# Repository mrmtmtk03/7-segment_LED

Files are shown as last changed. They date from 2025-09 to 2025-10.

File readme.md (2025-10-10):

# 7セグメントLED回路
## 回路構成
KiCadにて回路図を作成した。
7セグメントデコーダー([TC4511BP](https://toshiba.semicon-storage.com/jp/semiconductor/product/general-purpose-logic-ics/detail.TC4511BP.html))を使用して、4つの7セグメントLEDをArduino UNOによりダイナミック点灯する回路である。
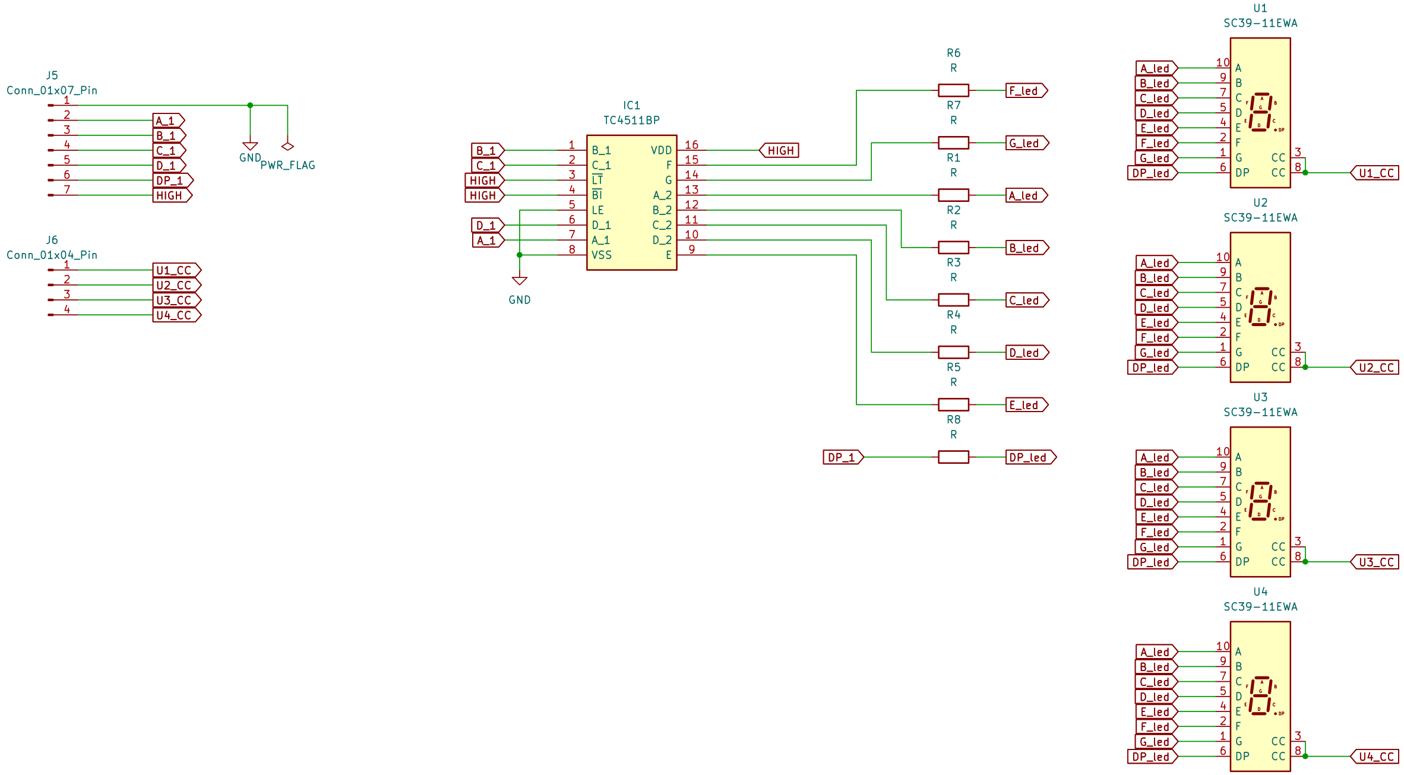
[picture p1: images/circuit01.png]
KiCadにて作成した回路図

## 使用部品
使用する7セグメントLEDはカソードコモンで、データシートより順方向電圧$`V_F=3.5\,[\mathrm{V}]`$、順方向電流の絶対最大定格は$`I_F=35\,[\mathrm{mA}]`$である。
今回は$`I_F=4.5\,[\mathrm{mA}]`$となるように抵抗1を選定し以下のようにRを330 Ωと定める。
```math
R_1=\frac{V-V_F}{I_F}=\frac{5-3.5}{0.0045}≒330\,[\mathrm{Ω}]
```
具体的な使用部品は以下の表に示す。
| 部品 | 型番 | 秋月電子販売コード |
| :--- | :--- | :---: |
| 7セグメントドライバー | TC4511BP | [114057](https://akizukidenshi.com/catalog/g/g114057/) |
| 7セグメントLED | OSL10391-LRA | [130319](https://akizukidenshi.com/catalog/g/g130319/) |
| 抵抗器 | 330 Ω | [107812](https://akizukidenshi.com/catalog/g/g107812/) |
| 丸ピンICソケット(16P) | 2227MC-16-03 | [100029](https://akizukidenshi.com/catalog/g/g100029/) |
| 細ピンヘッダー(オスL型) 1×12 | PHA-1x12RG | [111573](https://akizukidenshi.com/catalog/g/g111573/) |

なお、点灯させるためには、この他に[Arduino UNO](https://akizukidenshi.com/catalog/g/g115574/)が必要である。
## プリント基板の作成
設計した基板データは本リポジトリで公開している。
例えば、[JLCPCB](https://jlcpcb.com/)であればこの[ZIPファイル](7-segment_LED_02_kicad\production\7-segment_LED_02_kicad.zip) `7-segment_LED_02_kicad\production\7-segment_LED_02_kicad.zip`をgerber fileとしてアップロードすることで基板の発注ができる。

ただし、基板の発注内容に誤りがあった場合、その結果生じた発注者の不利益について、当方は責任を負いかねますので、十分ご注意ください。

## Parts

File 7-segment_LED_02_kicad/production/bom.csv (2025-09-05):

Designator | Footprint | Quantity | Value | LCSC Part #
GND | PinHeader_1x07_P2.54mm_Vertical | 1 | Conn_01x07_Pin
IC1 | DIP762W60P254L1975H445Q16N | 1 | TC4511BP
J6 | PinHeader_1x04_P2.54mm_Vertical | 1 | Conn_01x04_Pin
R1, R2, R3, R4, R5, R6, R7, R8 | R_Axial_DIN0207_L6.3mm_D2.5mm_P10.16mm_Horizontal | 8 | R
U1, U2, U3, U4 | Sx39-1xxxxx | 4 | SC39-11EWA

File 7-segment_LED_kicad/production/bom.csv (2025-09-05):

Designator | Footprint | Quantity | Value | LCSC Part #
GND | PinHeader_1x12_P2.54mm_Vertical | 1 | Conn_01x12_Pin
IC1 | DIP762W60P254L1975H445Q16N | 1 | TC4511BP
R1, R2, R3, R4, R5, R6, R7, R8 | R_Axial_DIN0207_L6.3mm_D2.5mm_P10.16mm_Horizontal | 8 | R
U1, U2, U3, U4 | Sx39-1xxxxx | 4 | SC39-11EWA

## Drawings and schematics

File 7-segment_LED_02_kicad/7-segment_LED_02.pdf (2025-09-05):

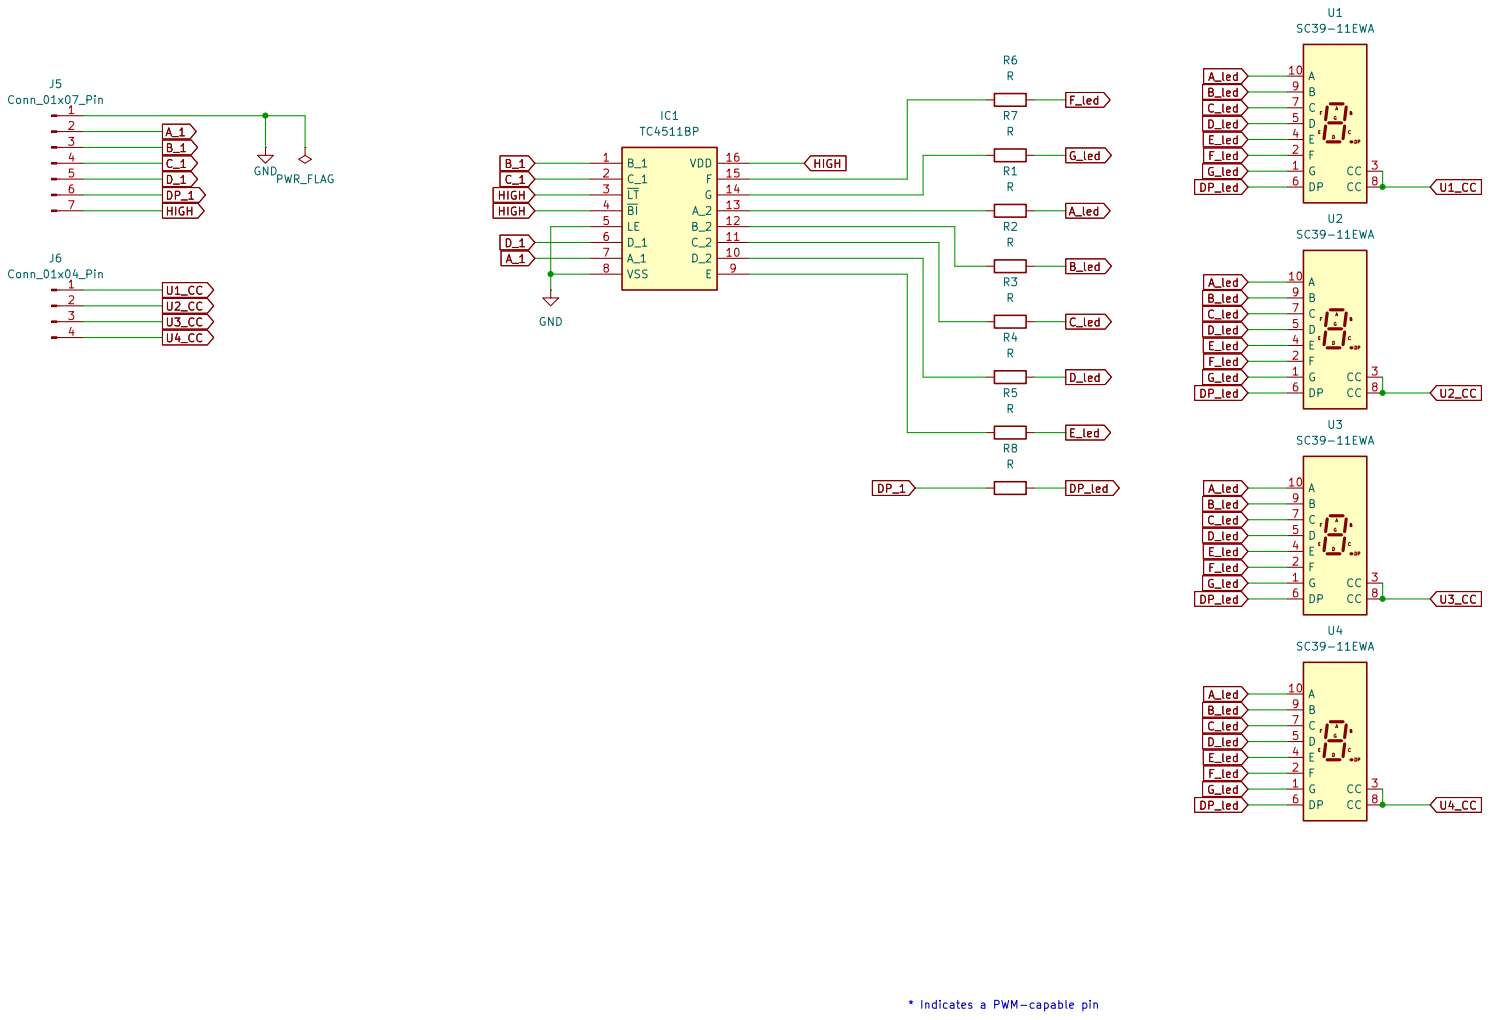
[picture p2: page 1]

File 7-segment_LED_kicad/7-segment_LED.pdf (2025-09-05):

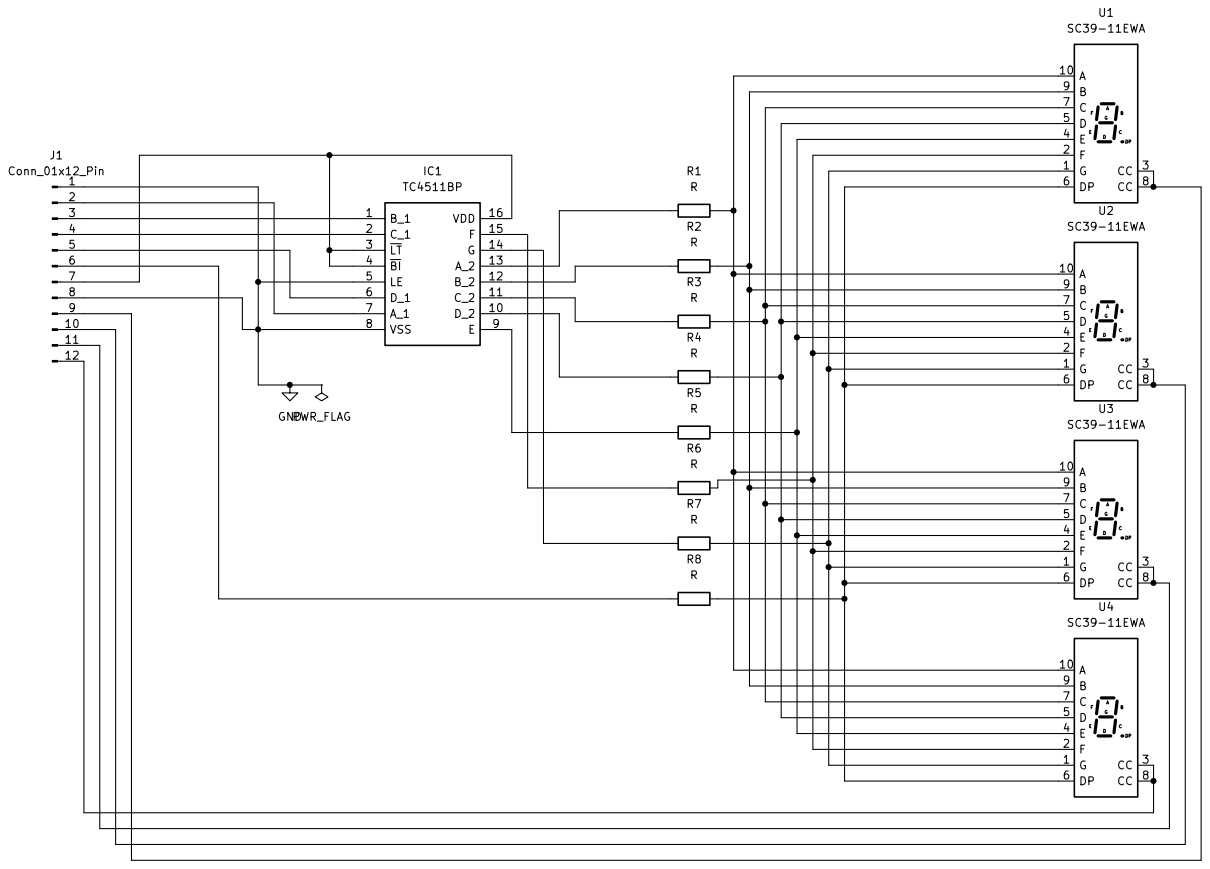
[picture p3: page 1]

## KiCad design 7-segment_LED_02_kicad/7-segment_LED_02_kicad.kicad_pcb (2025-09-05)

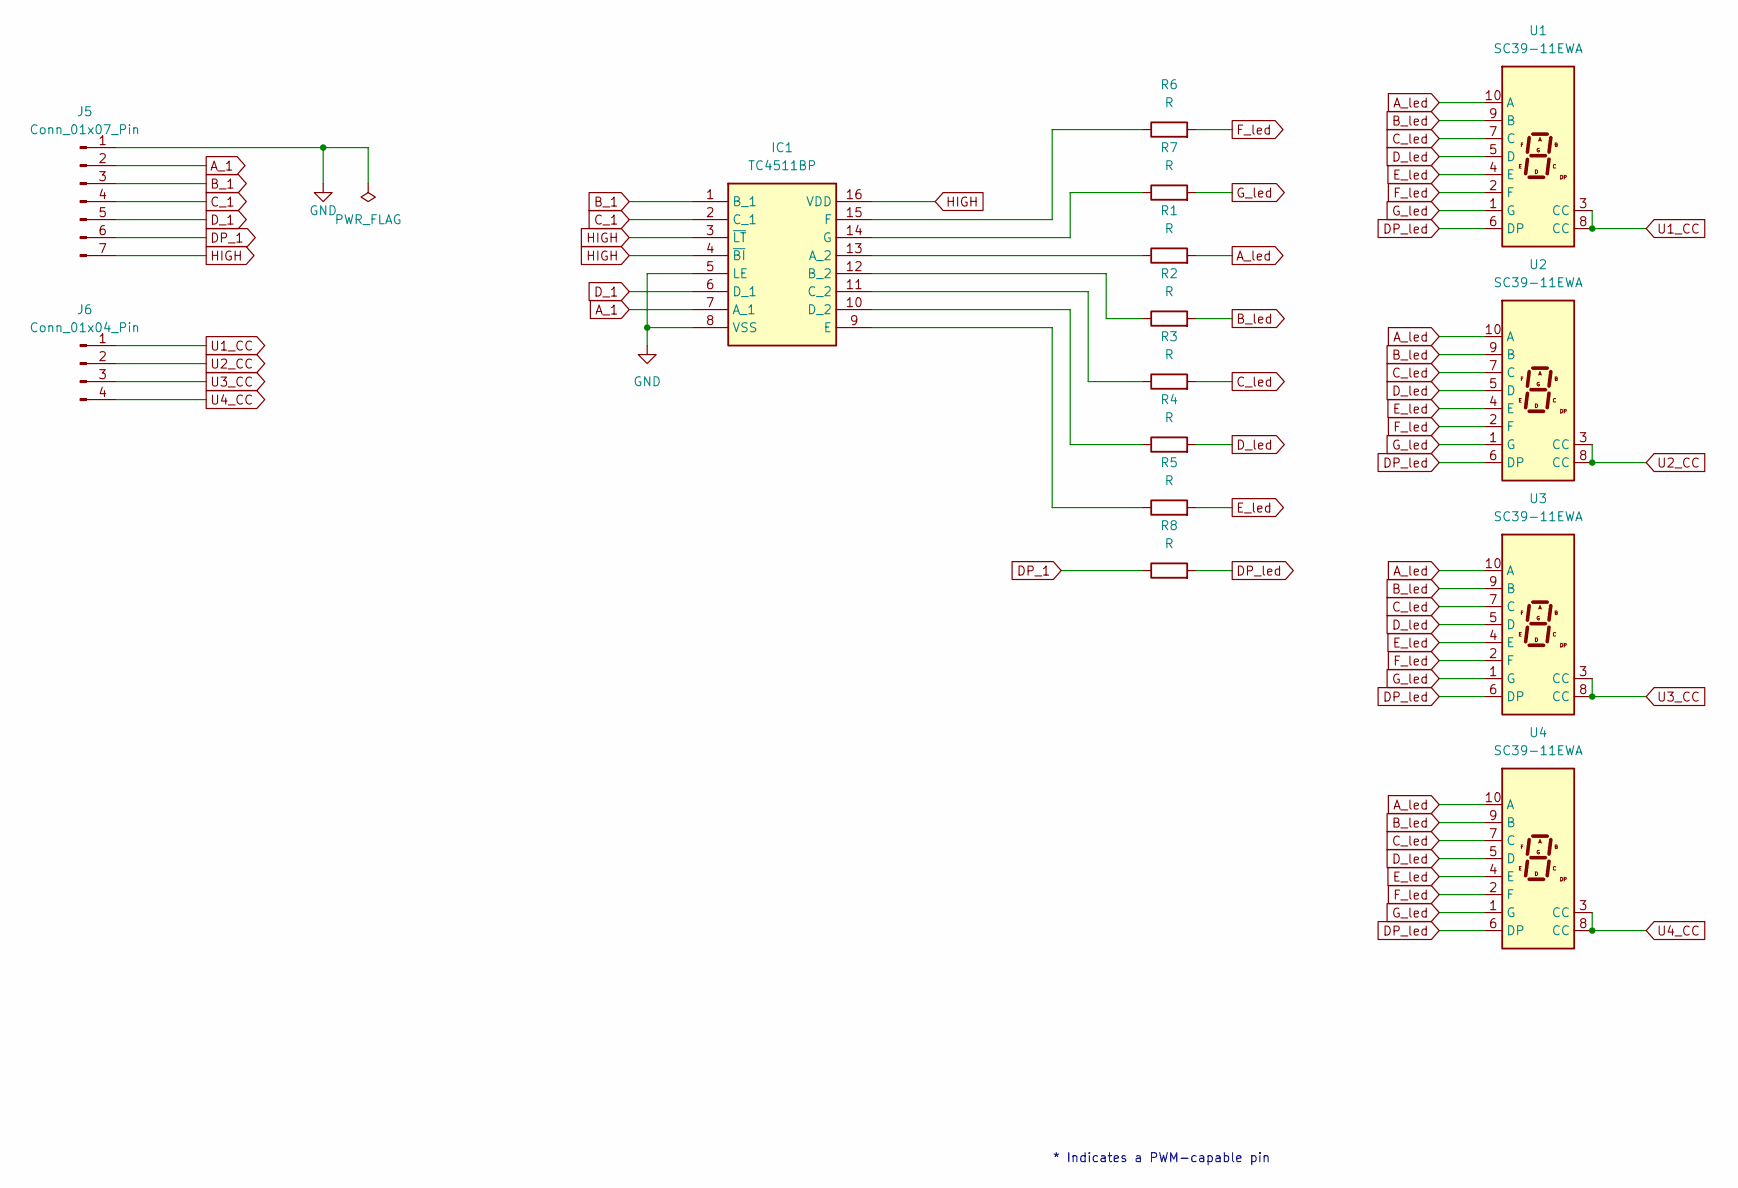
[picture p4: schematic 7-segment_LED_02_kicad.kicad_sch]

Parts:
IC1: TC4511BP; DIP762W60P254L1975H445Q16N; Manufacturer_Part_Number TC4511BP; Mouser Part Number N/A
J5: Conn_01x07_Pin; PinHeader_1x07_P2.54mm_Vertical
J6: Conn_01x04_Pin; PinHeader_1x04_P2.54mm_Vertical
R1, R2, R3, R4, R5, R6, R7, R8: R; R_Axial_DIN0207_L6.3mm_D2.5mm_P10.16mm_Horizontal
U1, U2, U3, U4: SC39-11EWA; Sx39-1xxxxx

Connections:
A_1: IC1.7 (A_1), J5.2; also elsewhere on the board
A_led: R1.2, U1.10 (A), U2.10 (A), U3.10 (A), U4.10 (A)
B_1: IC1.1 (B_1), J5.3; also elsewhere on the board
B_led: R2.2, U1.9 (B), U2.9 (B), U3.9 (B), U4.9 (B)
C_1: IC1.2 (C_1), J5.4; also elsewhere on the board
C_led: R3.2, U1.7 (C), U2.7 (C), U3.7 (C), U4.7 (C)
DP_1: J5.6, R8.1; also elsewhere on the board
DP_led: R8.2, U1.6 (DP), U2.6 (DP), U3.6 (DP), U4.6 (DP)
D_1: IC1.6 (D_1), J5.5; also elsewhere on the board
D_led: R4.2, U1.5 (D), U2.5 (D), U3.5 (D), U4.5 (D)
E_led: R5.2, U1.4 (E), U2.4 (E), U3.4 (E), U4.4 (E)
F_led: R6.2, U1.2 (F), U2.2 (F), U3.2 (F), U4.2 (F)
GND: IC1.5 (LE), IC1.8 (VSS), J5.1; also elsewhere on the board
G_led: R7.2, U1.1 (G), U2.1 (G), U3.1 (G), U4.1 (G)
HIGH: IC1.3 (~LT), IC1.4 (~BI), IC1.16 (VDD), J5.7; also elsewhere on the board
unnamed: IC1.13 (A_2), R1.1
unnamed: IC1.12 (B_2), R2.1
unnamed: IC1.11 (C_2), R3.1
unnamed: IC1.10 (D_2), R4.1
unnamed: IC1.9 (E), R5.1
unnamed: IC1.15 (F), R6.1
unnamed: IC1.14 (G), R7.1
U1_CC: J6.1, U1.3 (CC), U1.8 (CC)
U2_CC: J6.2, U2.3 (CC), U2.8 (CC)
U3_CC: J6.3, U3.3 (CC), U3.8 (CC)
U4_CC: J6.4, U4.3 (CC), U4.8 (CC)

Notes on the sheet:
* Indicates a PWM-capable pin

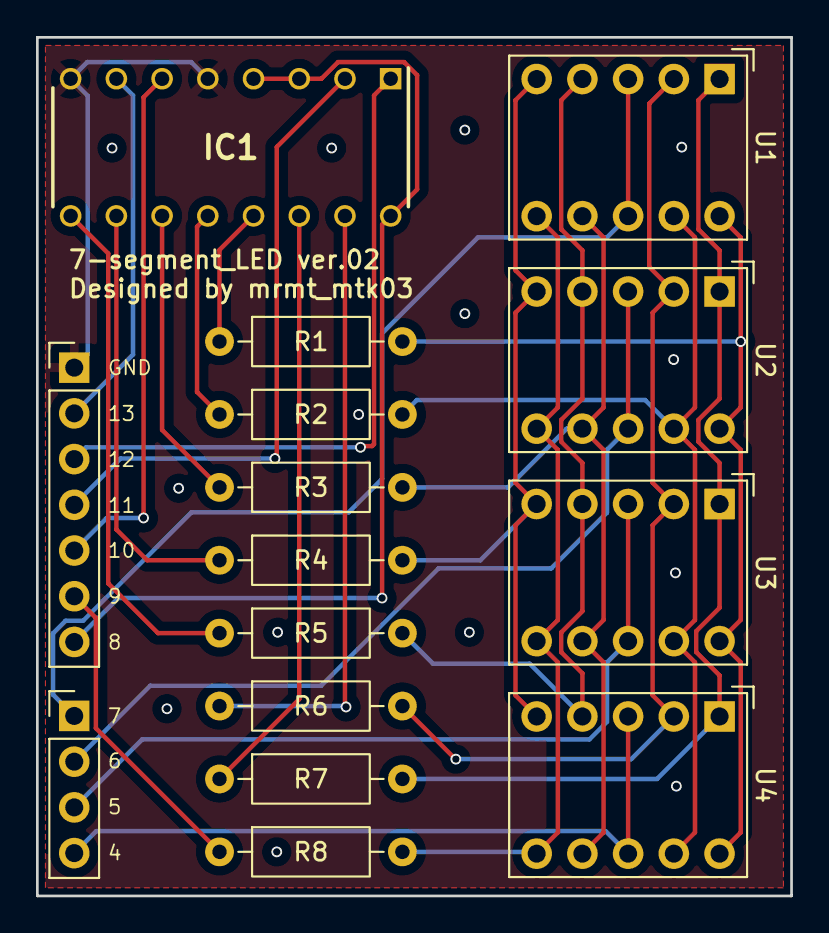
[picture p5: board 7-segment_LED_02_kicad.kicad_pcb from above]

Board: 2 copper layers, 41.9 x 47.7 mm, 15 parts (0 on the bottom side), 26 nets.

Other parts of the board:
GND: Conn_01x07_Pin; PinHeader_1x07_P2.54mm_Vertical

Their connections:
A_1: GND.2; also elsewhere on the board
B_1: GND.3; also elsewhere on the board
C_1: GND.4; also elsewhere on the board
DP_1: GND.6; also elsewhere on the board
D_1: GND.5; also elsewhere on the board
GND: GND.1; also elsewhere on the board
HIGH: GND.7; also elsewhere on the board

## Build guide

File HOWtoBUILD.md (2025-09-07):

# How to Build
## 必要な工具
- はんだごて
- はんだ
- ニッパー
- Arduino UNO
## 必要な部品
まずは、必要部品を確認する。
|部品|型番|個数|
|:--|:--|--:|
|本体基板|-|1|
|7セグメントドライバー|TC4511BP|1|
|7セグメントLED|OSL10391-LRA|4|
|抵抗器|330 Ω (本資料では75 Ωを使用)|8|
|丸ピンICソケット(16P)|2227MC-16-03|1|
|L型ピンヘッダー 1×7|-|1|
|L型ピンヘッダー 1×4|-|1|
## 組み立て
初めに最も背の低い抵抗器を取り付ける。330 Ωの抵抗器のカラーコードは「橙橙茶金」である。

抵抗器は極性がないため、どちら向きに差し込んでも構わない。

抵抗器を差し込んで裏側からはんだ付けする。余った抵抗器の足はニッパーで切り落とす。
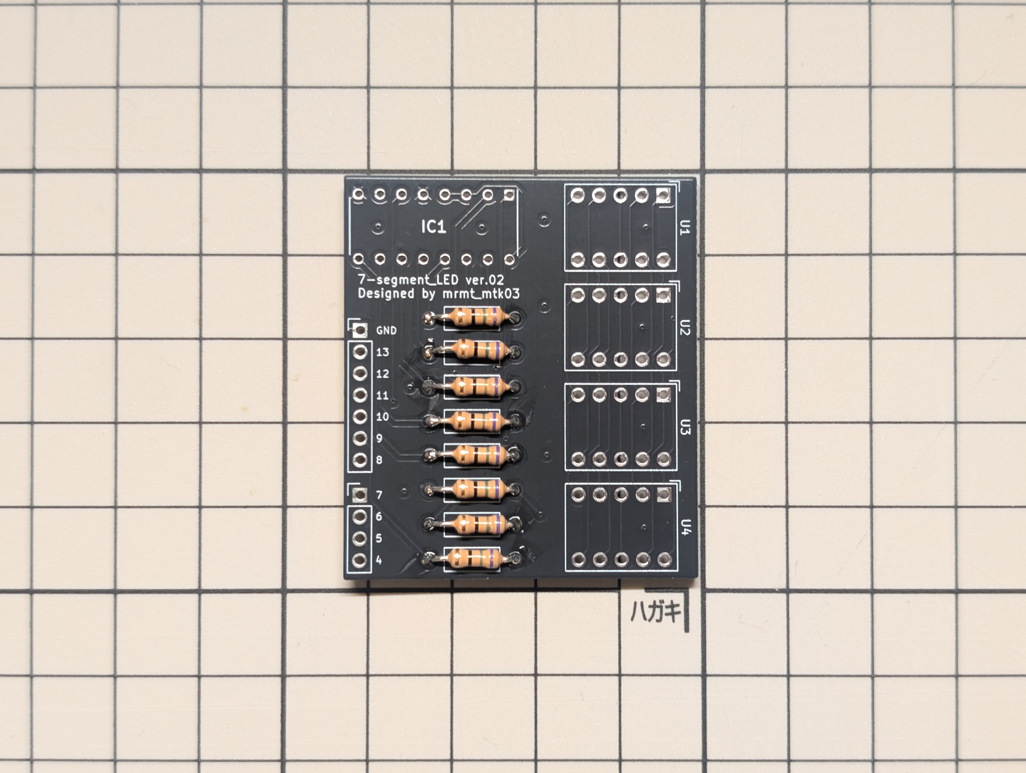
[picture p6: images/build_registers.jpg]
抵抗器をはんだ付け

次にピンヘッダーをはんだ付けする。固定するのが難しい場合はマスキングテープなどで仮止めしてからはんだ付けすると良い。

このピンヘッダーを介してArduino UNOを接続することになる。

次にピンソケットをはんだ付けする。このときピンソケットにある切り欠き部分(赤丸)が右側に来るように取り付けると良い。
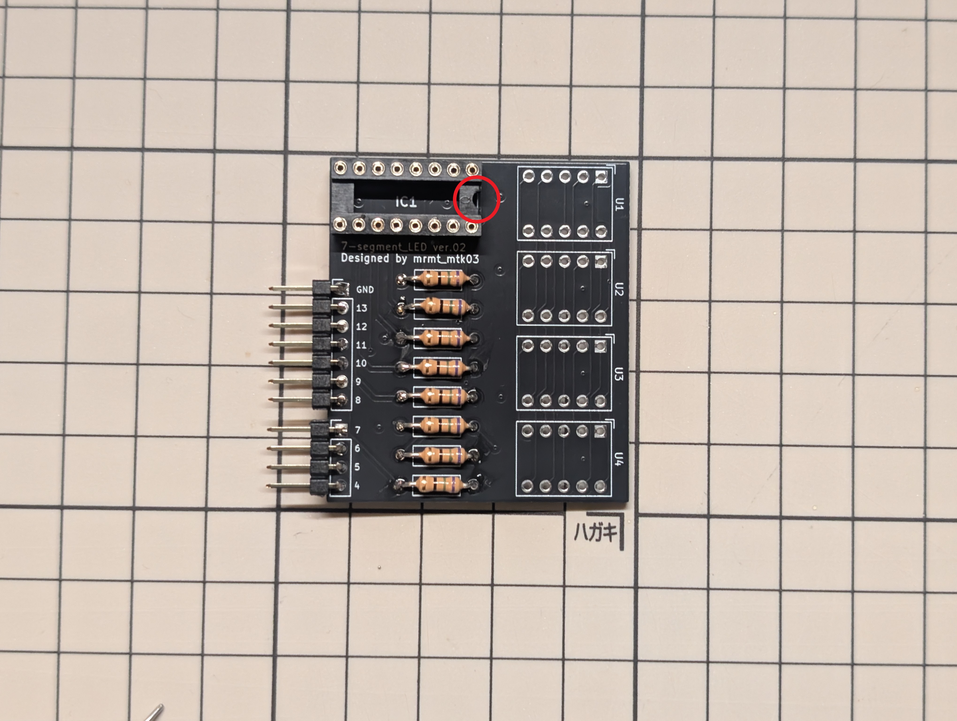
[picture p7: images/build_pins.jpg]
ピンヘッダとソケットをはんだ付け

7セグメントLEDをはんだ付けする。上下の向きを間違えると点灯しないので画像の向きになるように設置する。

これもマスキングテープなどで仮止めするとはんだ付けしやすい。
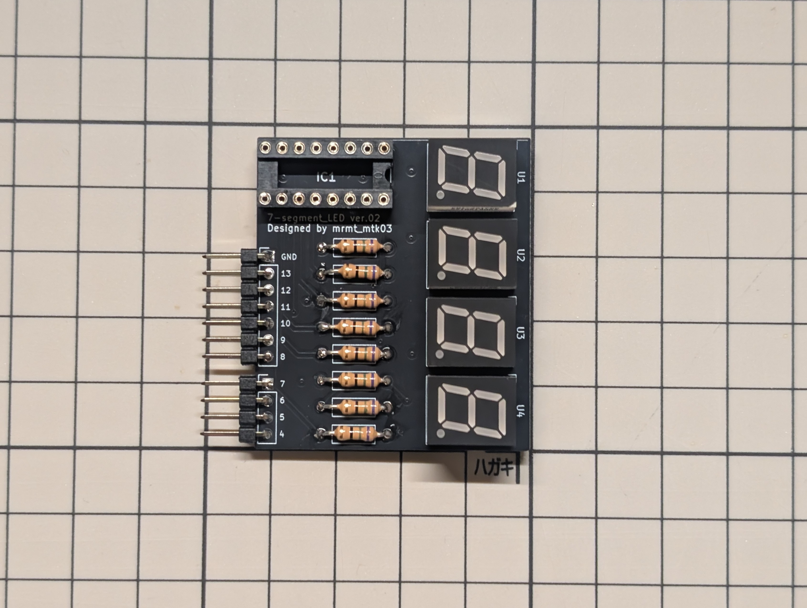
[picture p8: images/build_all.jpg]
7セグメントLEDをはんだ付け

最後にソケットに7セグメントドライバーIC(TC4511BP)を差し込む。

脚の間隔が合うように、少し指でICの脚を軽く曲げてやると差し込みやすい。
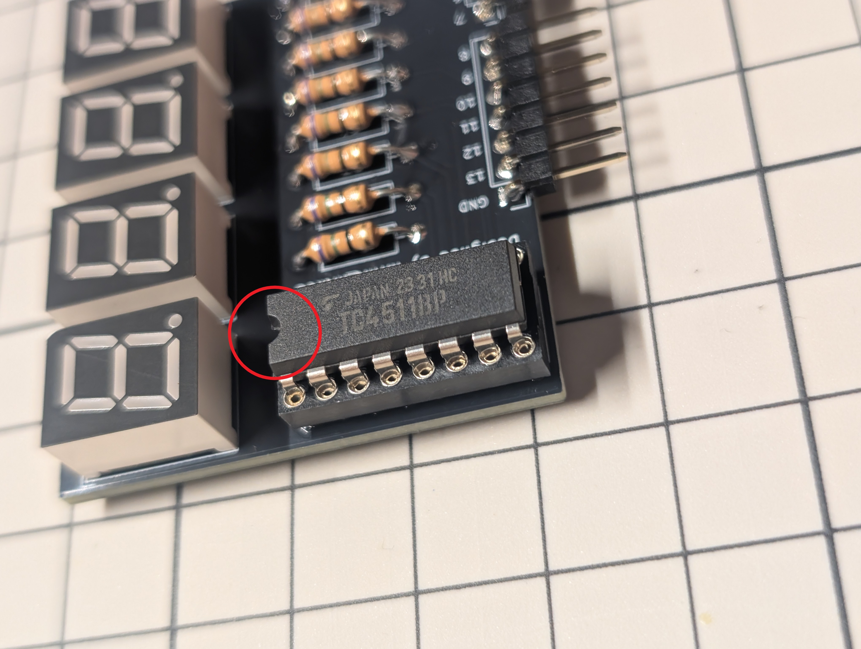
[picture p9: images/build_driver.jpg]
ICを差し込む

## 動作
動作させる場合は、まずArduino UNOにプログラムを書き込んでから本基板をArduinoと接続する。（Arduinoで何らかのプログラムが動作している可能性があり、本基板が破損するのを防ぐため）
### プログラムの書き込み
サンプルプログラムは [program_arduino](program_arduino)フォルダ に保存している。フォルダごとGithubからダウンロードして使用する。

ダウンロードしたプログラムファイルをArduino IDEで開き、手持ちのArduino UNOに書き込む。

書き込む際は「ツール」タブから「ボード:Arduino UNO」を選択し、ポートは適切なCOMポートになっていることを確認する。
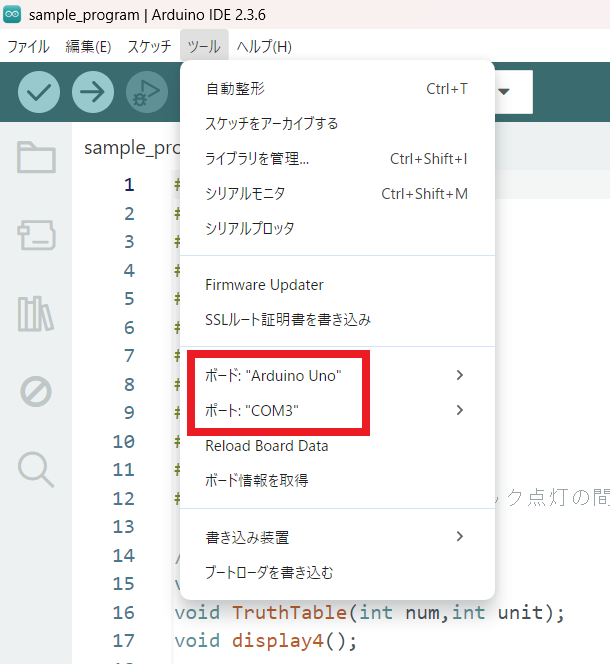
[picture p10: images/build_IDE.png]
IDE設定

### 基板の接続
正常に書き込みが完了したら、Arduinoと基板を接続する。

接続の際はデジタル入出力ピンの4番から13番およびその隣のGNDに基板のL型ピンヘッダが対応するように接続する。
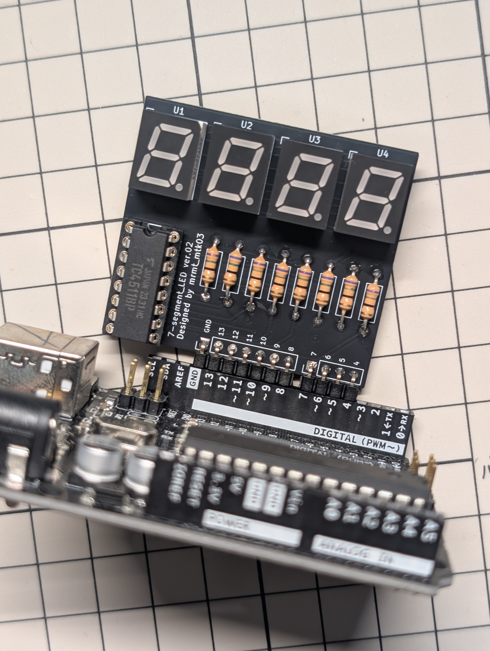
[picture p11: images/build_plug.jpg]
接続方法


## サンプルプログラム解説
作成予定

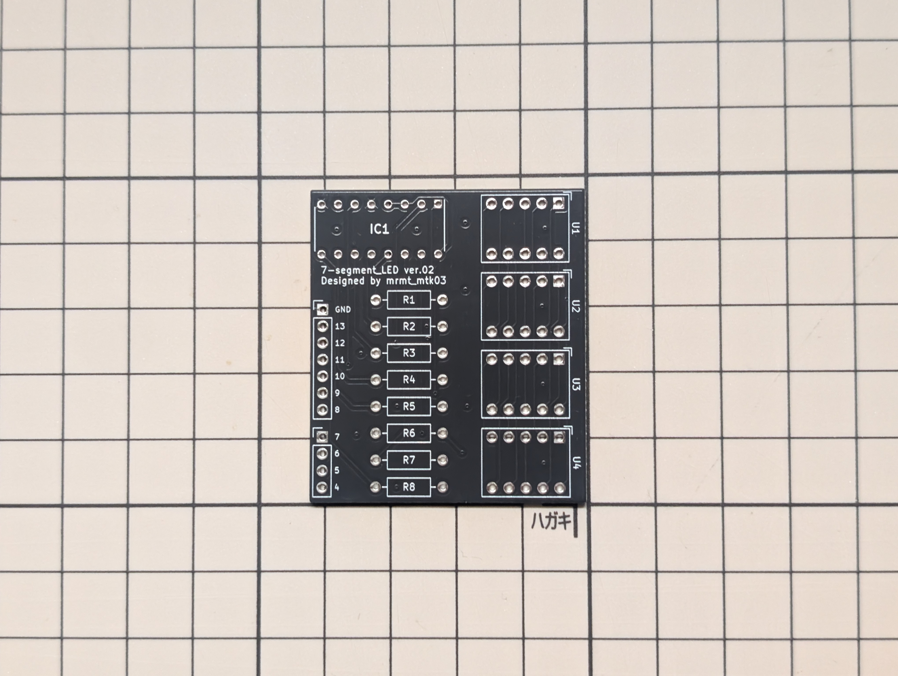
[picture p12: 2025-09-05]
images/build_init.jpg

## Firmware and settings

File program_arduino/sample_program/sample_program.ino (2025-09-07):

#include <MsTimer2.h>
#define pin_A 13
#define pin_B 12
#define pin_C 11
#define pin_D 10
#define pin_dot 9
#define VDD 8
#define U1 7
#define U2 6
#define U3 5
#define U4 4
#define DT 2    // ダイナミック点灯の間隔(ms)

// 関数のプロトタイプ宣言
void initinal_pins();
void TruthTable(int num,int unit);
void display4();

// グローバル変数定義
int display_num=0000;     // 0から9999までの整数
int dot_count=0;
int display_array[4]={0};
int display_input[4][4]={0};
int display_dot[4]={0};

void setup() {
  Serial.begin(9600);
  initinal_pins();
  Serial.print("SYSTEM START!!!\n");
  // タイマー割り込みを開始
  MsTimer2::set(1000, digitToDisplayData);
  MsTimer2::start();
}

void loop() {
  display4();
}

void digitToDisplayData(){
  display_num++;
  if(display_num<0){
    display_num=0;
  }
  if(display_num==9999){
    display_num=0;
    dot_count++;
    if(dot_count>16){
      dot_count=0;
    }
  }
  // display_numを各桁の要素に分解
  display_array[0]=display_num/1000;
  display_array[1]=(display_num/100)%10;
  display_array[2]=(display_num/10)%10;
  display_array[3]=display_num%10;
  // 真理値表に代入
  TruthTable(display_array[0],1);
  TruthTable(display_array[1],2);
  TruthTable(display_array[2],3);
  TruthTable(display_array[3],4);
  // dot処理
  dotTable(dot_count);
}

void display4(){
  // ユニット1
  digitalWrite(U1,LOW);
  digitalWrite(pin_A,display_input[0][0]);
  digitalWrite(pin_B,display_input[0][1]);
  digitalWrite(pin_C,display_input[0][2]);
  digitalWrite(pin_D,display_input[0][3]);
  digitalWrite(pin_dot,display_dot[3]);
  delay(DT);
  digitalWrite(U1,HIGH);
  // ユニット2
  digitalWrite(U2,LOW);
  digitalWrite(pin_A,display_input[1][0]);
  digitalWrite(pin_B,display_input[1][1]);
  digitalWrite(pin_C,display_input[1][2]);
  digitalWrite(pin_D,display_input[1][3]);
  digitalWrite(pin_dot,display_dot[2]);
  delay(DT);
  digitalWrite(U2,HIGH);
  // ユニット3
  digitalWrite(U3,LOW);
  digitalWrite(pin_A,display_input[2][0]);
  digitalWrite(pin_B,display_input[2][1]);
  digitalWrite(pin_C,display_input[2][2]);
  digitalWrite(pin_D,display_input[2][3]);
  digitalWrite(pin_dot,display_dot[1]);
  delay(DT);
  digitalWrite(U3,HIGH);
  // ユニット4
  digitalWrite(U4,LOW);
  digitalWrite(pin_A,display_input[3][0]);
  digitalWrite(pin_B,display_input[3][1]);
  digitalWrite(pin_C,display_input[3][2]);
  digitalWrite(pin_D,display_input[3][3]);
  digitalWrite(pin_dot,display_dot[0]);
  delay(DT);
  digitalWrite(U4,HIGH);
}

void TruthTable(int num,int unit){
  if(num%2==0){
    display_input[unit-1][0]=0;
  }
  else{
    display_input[unit-1][0]=1;
  }
  if(num%4<2){
    display_input[unit-1][1]=0;
  }
  else{
    display_input[unit-1][1]=1;
  }
  if(num%8<4){
    display_input[unit-1][2]=0;
  }
  else{
    display_input[unit-1][2]=1;
  }
  if(num<8){
    display_input[unit-1][3]=0;
  }
  else{
    display_input[unit-1][3]=1;
  }
}

void dotTable(int count){
  if(count%2==0){
    display_dot[0]=0;
  }
  else{
    display_dot[0]=1;
  }
  if(count%4<2){
    display_dot[1]=0;
  }
  else{
    display_dot[1]=1;
  }
  if(count%8<4){
    display_dot[2]=0;
  }
  else{
    display_dot[2]=1;
  }
  if(count<8){
    display_dot[3]=0;
  }
  else{
    display_dot[3]=1;
  }
}

void initinal_pins(){
  pinMode(pin_A,OUTPUT);
  pinMode(pin_B,OUTPUT);
  pinMode(pin_C,OUTPUT);
  pinMode(pin_D,OUTPUT);
  pinMode(pin_dot,OUTPUT);
  pinMode(VDD,OUTPUT);
  pinMode(U1,OUTPUT);
  pinMode(U2,OUTPUT);
  pinMode(U3,OUTPUT);
  pinMode(U4,OUTPUT);
  digitalWrite(pin_A,LOW);
  digitalWrite(pin_B,LOW);
  digitalWrite(pin_C,LOW);
  digitalWrite(pin_D,LOW);
  digitalWrite(pin_dot,LOW);
  digitalWrite(VDD,HIGH);
  digitalWrite(U1,HIGH);
  digitalWrite(U2,HIGH);
  digitalWrite(U3,HIGH);
  digitalWrite(U4,HIGH);
}

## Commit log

2025-09-05 7-segment_LEDをアップロード
    [7-segment_LED.kicad_pcb, 7-segment_LED.kicad_sch, 7-segment_LED_02_kicad.kicad_pcb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]
2025-09-05 HOWtoBUILD.mdの組み立て手順を整理し、説明を追加
2025-09-07 Update HOWtoBUILD.md
    プログラムの書き込みについて修正
2025-09-07 組み立て画像を追加
2025-09-07 サンプルプログラム解説セクションを追加
2025-09-07 サンプルプログラム解説を作成予定として追記
2025-09-07 build_plug.jpgの更新
2025-09-30 readme.mdを作成
2025-10-10 プリント基板の作成に関する情報を追加
